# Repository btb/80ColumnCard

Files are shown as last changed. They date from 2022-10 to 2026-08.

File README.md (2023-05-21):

# 80ColumnCard
An 80-Column Card for the Apple II, II+, and clones.

This is mostly a clone of the Videx Videoterm, with some changes to reduce the number of chips needed.

[Interactive BOM](https://btb.github.io/80ColumnCard/hardware/80ColumnCard/bom/80ColumnCard_0.html)

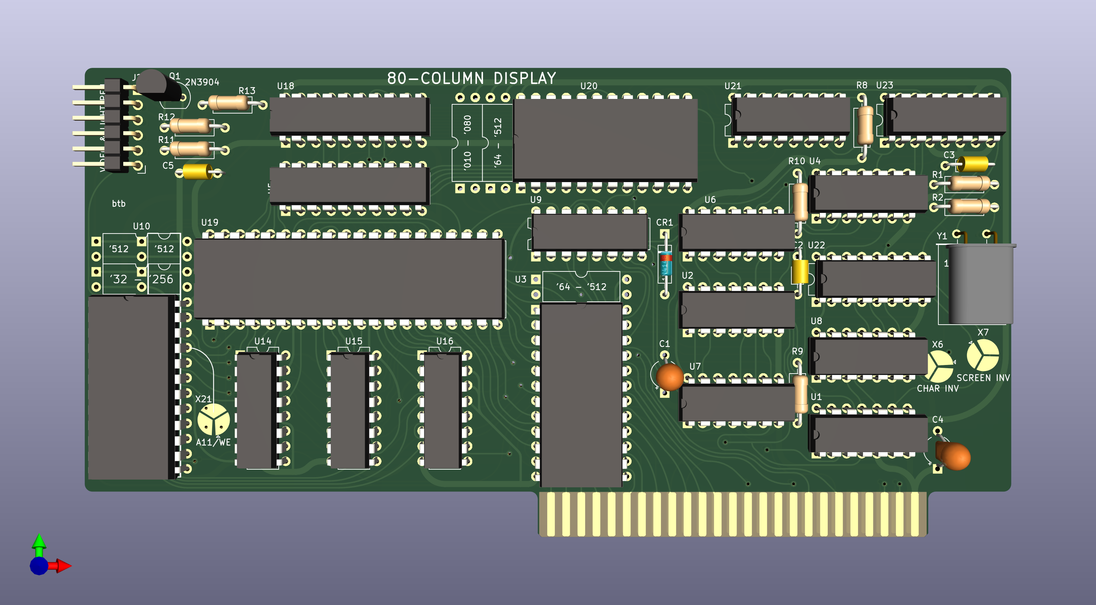
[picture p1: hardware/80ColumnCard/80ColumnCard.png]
rendering of 80 Column Card circuit board


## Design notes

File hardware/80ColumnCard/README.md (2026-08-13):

# 80ColumnCard

## Construction notes

## RAM (U10)
U10 is designed to use a 6116 Static RAM chip, however there are multiple overlapping footprints available on the board in order for you to just use whatever 2K or larger SRAM is easiest for you to obtain. Consult the interactive BOM if you're not sure how to place the chip. Many larger chips however have the A11 pin where the 6116 has the /WE pin, so you'll have to cut and then re-solder the X21 jumper accordingly.

## Firmware ROM (U3)
U3 holds the 1K of firmware (e.g. "Videx Videoterm ROM 2.4.bin") and can be any EPROM from a 2758A up to a 27(C)512, depending on whatever you have available. A10 will be permanently tied low, and A11-A15 are all permanently tied high, so the code needs to go in the lower 1K of a 2716, or the lower half of the top 2K of any larger EPROM. (Or just repeat it enough times to fill up the whole thing)

## Character ROM (U20)
Any size from 2732 to 27C512 (27C080 on rev0) is pin-compatible, however the character generator subcircuit appears to be very sensitive to the speed of this EPROM. Character corruption occurs with EPROMs that are too fast, so 200ns or slower (higher number) is recommended.
Confirmed working are: M27C64-20, AM2732A-2.

This EPROM can hold one or two of the 2K [character sets](../../character_roms). A12-A15 are all permanently tied high, so only the top 4K of the EPROM is usable. The standard character set (e.g. "videx std 7x9 - top right.bin") goes in the lower 2K of that space, and any desired alternative character set (e.g. "videx inverse - top left.bin") goes in the upper 2K of that space.

## Other
Although many of the TTL LS chips can be substituted with members of newer logic families (ACT, for example), U2 (74LS02) U4 (74LS04) U6 (74LS00) U23 (74LS161) must be LS or other TTL (non-CMOS) families.

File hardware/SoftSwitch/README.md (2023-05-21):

# SoftSwitch

A clone of the [Videx Soft Video Switch](../../documents/videx_soft_video_switch_manual.pdf)

[Interactive BOM](https://btb.github.io/80ColumnCard/hardware/SoftSwitch/bom/)

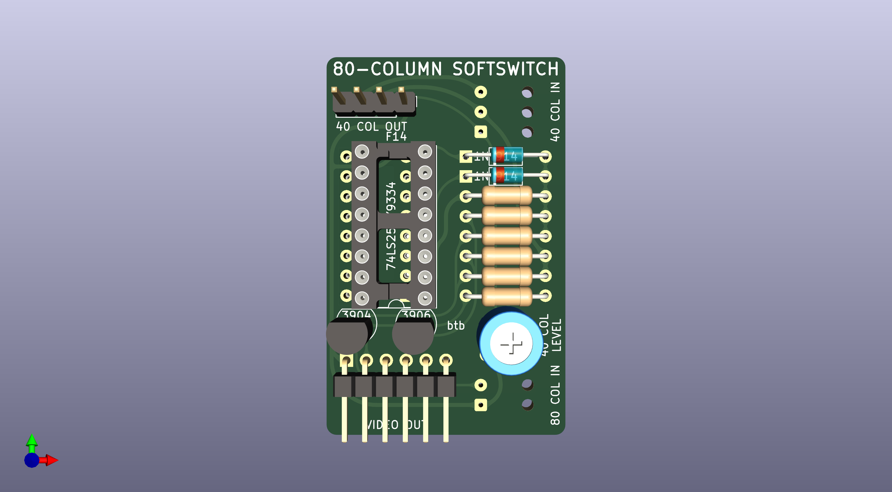
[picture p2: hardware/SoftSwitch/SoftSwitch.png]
rendering of SoftSwitch circuit board


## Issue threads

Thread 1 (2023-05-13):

Soft switch BOM doesn't display properly

baldrick1, 2023-05-13:
It appears you uploaded an html file for the soft switch BOM that's interactive.  But Github tries to display it as Raw HTML in its ecosystem.  Downloading the html file and opening it locally doesn't link to the actual data on the web.

btb, 2023-05-21:
Thanks for pointing that out. It is viewable through github.io, or it would have been if there wasn't a merge error in the file. It's now working at https://btb.github.io/80ColumnCard/hardware/SoftSwitch/bom/

Closed 2023-06-23.

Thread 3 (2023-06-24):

Finally built an 80 col card but the video is way out of sync and duplicated 4 times what could be the issue?

Verault, 2023-06-24:
So I finally got around to building one of the 80 col cards. When I do a pr#3 to go into 80 col mode the Sync is way, way off. I need to dial H Hold on my monitor to almost the extreme end to clear up video and as you can see from these photos the video output is duplicated in each corner of the screen. I can see a cursor but when I type it moves but there are no characters. I even tried using the roms from my original Videx card but it still is behaving thr same with those roms.

You can see the cursors on the inverse image. There are 4 cursors. And the non inverse image seems to be bouncing so the cursors ares slightly above each other. I circled them as to make them easier to see:
https://photos.app.goo.gl/85neNsyjyXsYRc43A
and
https://photos.app.goo.gl/yVLtZP9ghEdJ4nYZ8

A friend of mine is also building thr card. We ordered thr pcbs together. I am waiting on how his card behaves and will post back.

Again what is the issue here and why does the H Hold need to be completely adjusted out to get a video?

btb, 2023-06-24:
Interesting - can you tell me which firmware and what frequency crystal did you use?

The timings stored in different versions of firmware can vary and different timings may be needed for different monitors but I'm not sure it would result in this kind of problem. Still, you might want to see how it performs on different monitors just to check.

The sync circuitry is not very complicated, going directly from the 6845 (U19), pins 39 and 40, into the 74LS02 (U2) pins 2 and 3, out pin 1, and through R10, then it's mixed with the pixel data itself and goes into the output transistor Q1.

One possibility is that the 6845 just isn't outputting one of the sync signals - can you try swapping it? Same with the 74LS02.

I'm not much of an expert on the analog side of things, but the "mixing" of the sync with the pixel data is just a very simple voltage adder (averager) that could possibly be sensitive to the exact components used. Are U1 and U2 74LS series chips or something different like 74HCT? Can you verify the values of R9, R10, R11, R12, and R13? Replacing Q1 might be something to try if nothing else seems amiss.

Verault, 2023-06-24:
Ok. So for the firmware I used the Videx Videoterm ROM 2.4.bin and for the char rom I used the videx-std-7x9-topright.bin and the videx-inverse-topleft.bin with the std 7x9 rom being in the lower part of the eprom and teh videx inverse being in the top portion of the eprom. I used the bin files right from your github download and not outside files.

I am not using a softswitch.

I am using used 6845 IC's I bought online and have tried several. I even tried the one form my working videx card.. no change. ( I also swapped the used ones I bought on the original videx card and verified they were working.

I tested the 74ls03 and 74ls86 but I can try swapping them for a different brand just because I have plenty.

For reference U1 is a hitachi HD74ls86p and U2 is a generic 74ls02N

R9 is a 1.47K (1.5K) Ohm
r10 2K Ohm
r11 10 Ohm
r12 150 Ohm
r13 218 Ohm (I must have used a 220 ohm instead of a 200 ohm)

I was wondering if Q1 could be the issue. I can try swapping it for another 2N3904.

Just for reference I am using a Zenith monochrome composite monitor. Its my bench monitor and I used it for everything. I have plenty of other monitors I can try just to say we did that however I  jut want to point out that this zenith monitor outputs from my actual Videx card good 80 col video without having to adjust the H hold at all.

btb, 2023-06-24:
None of that seems amiss. I think that's the exact same crystal I used as well.

I do have a working card that I built and used with a Monitor III. You used my gerbers_0.zip file, right?

I just realized I missed in the original post that you have a real videx card and tried swapping the roms - As far as I know, the real Videx cards all used a 2708 EPROM for the firmware and you can't swap to a 2716 or similar without modifying the card. This could potentially have damaged your EPROM?

What eproms and sram chips are you using?
I only recently added this wiki page to clarify some things about the different chip requirements and where the data has to go, did you happen to see it?
https://github.com/btb/80ColumnCard/wiki/Parts

Verault, 2023-06-25:
The original Roms went back in the videx card and its still working perfectly fine.

The sram is HM6116L-70  12 pin

The eproms I am using are your run of the mill 27C64 which I have lots of. Like I mentioned I used your recommendation on the PARTS wiki and have the videx std 7 x 9 bin in the lower part of the eprom and the videx inverse in the top of the eprom. If there is a way I can upload or share the bin I created I can.

I have seen your PARTS wiki and have the 6116 in the lowest part of the socket down at the bottom of the board.

The only thing I was unsure about was the cutting of X21 jumper for A11. I didnt think my 6116 qualified for that.

btb, 2023-06-26:
You should be able to drop files here and I can look at them, yes. If you want to email me directly, it's bradley.bell at gmail.

You shouldn't need to change the jumper for a 6116.

Verault, 2023-06-26:
I wasnt aware I could add them here.
[Videx80colroms.zip](https://github.com/btb/80ColumnCard/files/11875155/Videx80colroms.zip)
These bins were made to use 27c64 eproms.

ryucats, 2023-06-27:
I've spent a week trying to get this card working, just managed to do so, and documented it in this pull request: https://github.com/btb/80ColumnCard/pull/4

I suspect that the horizontal timing in the firmware binary you're using is not playing nicely with your monitor; the same thing happened to me.  The timing data in the binary included in the firmware/ subdirectory is not stock; the pull request includes a .s file that can be modified to easily generate a binary with modified timing.

(most of the rest of the parts were scavenged from a faulty Sekom Videx clone, so I don't think your parts are bad, just that your timing parameters are incompatible with your monitor)

Not included in the pull request is a python script I wrote to derive timing register values from basic parameters -- I didn't include it because my problem turned out to be a) a character generator EPROM that was too fast and b) an incorrect assumption that the timing in the .bin in the firmware/ subdirectory was unmodified.  I can pass that script along if you want to play with it.

btb, 2023-06-27:
yeah, those files should work. That risk of damage I think would only be if you put your newly-burned ROM into your original Videx but it doesn't sound like you did that. (and a 2764 wouldn't fit of course!)

My apologies for the trouble you're having, I'm really not sure what the problem is. I'm used to just building things for myself, putting them out there for everyone else is kinda new for me. Maybe you could send me your card and I'll get it working for you. That would allow me to see what the pitfalls happen to be so others will avoid it.

ryucats, 2023-06-27:
Just had a look at the timing in the zipfile you attached.  At offset $A1, you have:

`7a 50 5e 2f 22 00 18 1d 00 08 e0 08 00 00 00 00`

Try:

`7b 50 5e 29 1b 08 18 19 00 08 e0 08 00 00 00 00`

... which is per the Videx documentation and fixed my horizontal sync issues.

btb, 2023-06-27:
Yeah, that's worth a try. That may fix the sync issue, and then a slower character ROM is needed to get the characters to show up...

I used an old 27C32 in mine, and it looks like @ryucats used a M27C64-200.

btb, 2023-06-27:
Sounds like you may have already tried U20 from your videx card in the new card and it didn't result in visible characters - but that might have been because it's a 2716 and those isn't supported on this card (A11 is needed to switch between standard and alternate character sets, and that line will instead go to VPP on a 2716) - but it is possible that that the Videx character rom chip will work, but only when you tell the card to use the alternate character set.

ryucats, 2023-06-27:
>Wouldn't they still expect to see some signs of characters even if the timing is wrong?

Independent of timing issues, If @verault is using a too-fast character EPROM, or a 2716 as you noted, then he'd either see garbage or a blank screen (except for the cursor) ... which is exactly what those pictures appear to be.
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
btb, 2023-06-28:
I double-checked on my card and it is using the
    7a 50 5e 2f 22 00 18  1d 00 08 e0 08 00 00 00 00
timings, and it definitely works on my Monitor IIe, FWIW. Doesn't work on the LCD tv I just picked up though.

Verault, 2023-06-28:
Sorry for not chiming back in. I have been ill. Good to see alot of discussion about the issue. I am going to try the new code in the firmware first. (By the way which rom are we talking about U20 or U3?)

Also I guess the eprom latency makes sense being an issue but this creates a huge problem of its own. I buy alot of eproms and MOST of them work, but have been re-badged. For instance my 27c64 eproms all say ST brand 27c64 but thier Chip ID's come up with a bunch of different manufacturers. So how can I possible find a trustworthy M27C64-200 with 200 latency? Do you possibly have a source I can purchase from thats reputable?

btb, 2023-06-28:
Here's a copy of the firmware for U3, with the stock timings and ready to go on a 2764
[Videx_Videoterm_ROM_2.4-stocktimings-2764.bin.zip](https://github.com/btb/80ColumnCard/files/11899147/Videx_Videoterm_ROM_2.4-stocktimings-2764.bin.zip)

Verault, 2023-06-28:
Thank you. And just to confirm the only eprom which is sensitive to latency is u20?

Verault, 2023-07-07:
Ok @btb and @ryucats I am sorry for the delay in replying but I have more info. I had a friend of mine who is building the same 80 col board mail it to me so I can test his as well. ITs basically behaving the same as mine except his is showing 6 screens (and again no characters) see photo.
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

Im at a complete loss on this. I have MANY MANY eproms of various sizes but like I said most have been relabeled so the only way to know the actual brand is to read the CHIP ID in my eprom programmer but that wont tell me the latency/speed.  I bought some AMD 27c512-200DC (thats 200ns correct) and I am getting the same exact image,.,, multiple screens inverted, no characters, very much out of sync.

@ryucats I have tried the stock and the timings you recommended. Please see the newest bins I burned , ill attach them here.

Did I mess up in making them?

I really want these boards to work but I dont know what is wrong at this point. I tried many eproms. I even tried some SST 27SF256 EEPROMS with the same results.

btb, 2023-07-07:
send me your address and I'll mail you a couple of known-working character roms

Verault, 2023-07-08:
Thank you. I just emailed you.

btb, 2023-08-01:
Well we found the problem on Verault's card, and it was due to a "bad" 74LS04 chip.
I have some of the same chips in my collection and they don't work for me either, It's possible these are counterfeit chips being sold as LS when they are actually some other type of logic. This is what they look like:
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

The 74LS04 is used in the clock circuit, which is another sensitive area. Possibly these chips, or a wider range of logic families, could be made to work with different values of C3 or R1 and R2.

Verault, 2023-09-08:
BTB is correct. The issue was the 74ls04 chips. They must be some relabeled nonsense from China. They test fine but dont work properly in this card. I ordered new ones from Jameco and they work fine, as the one I received back from BTB. Thank you so much for your help. That was an odd one. Issue resolved.

Closed 2023-09-08.

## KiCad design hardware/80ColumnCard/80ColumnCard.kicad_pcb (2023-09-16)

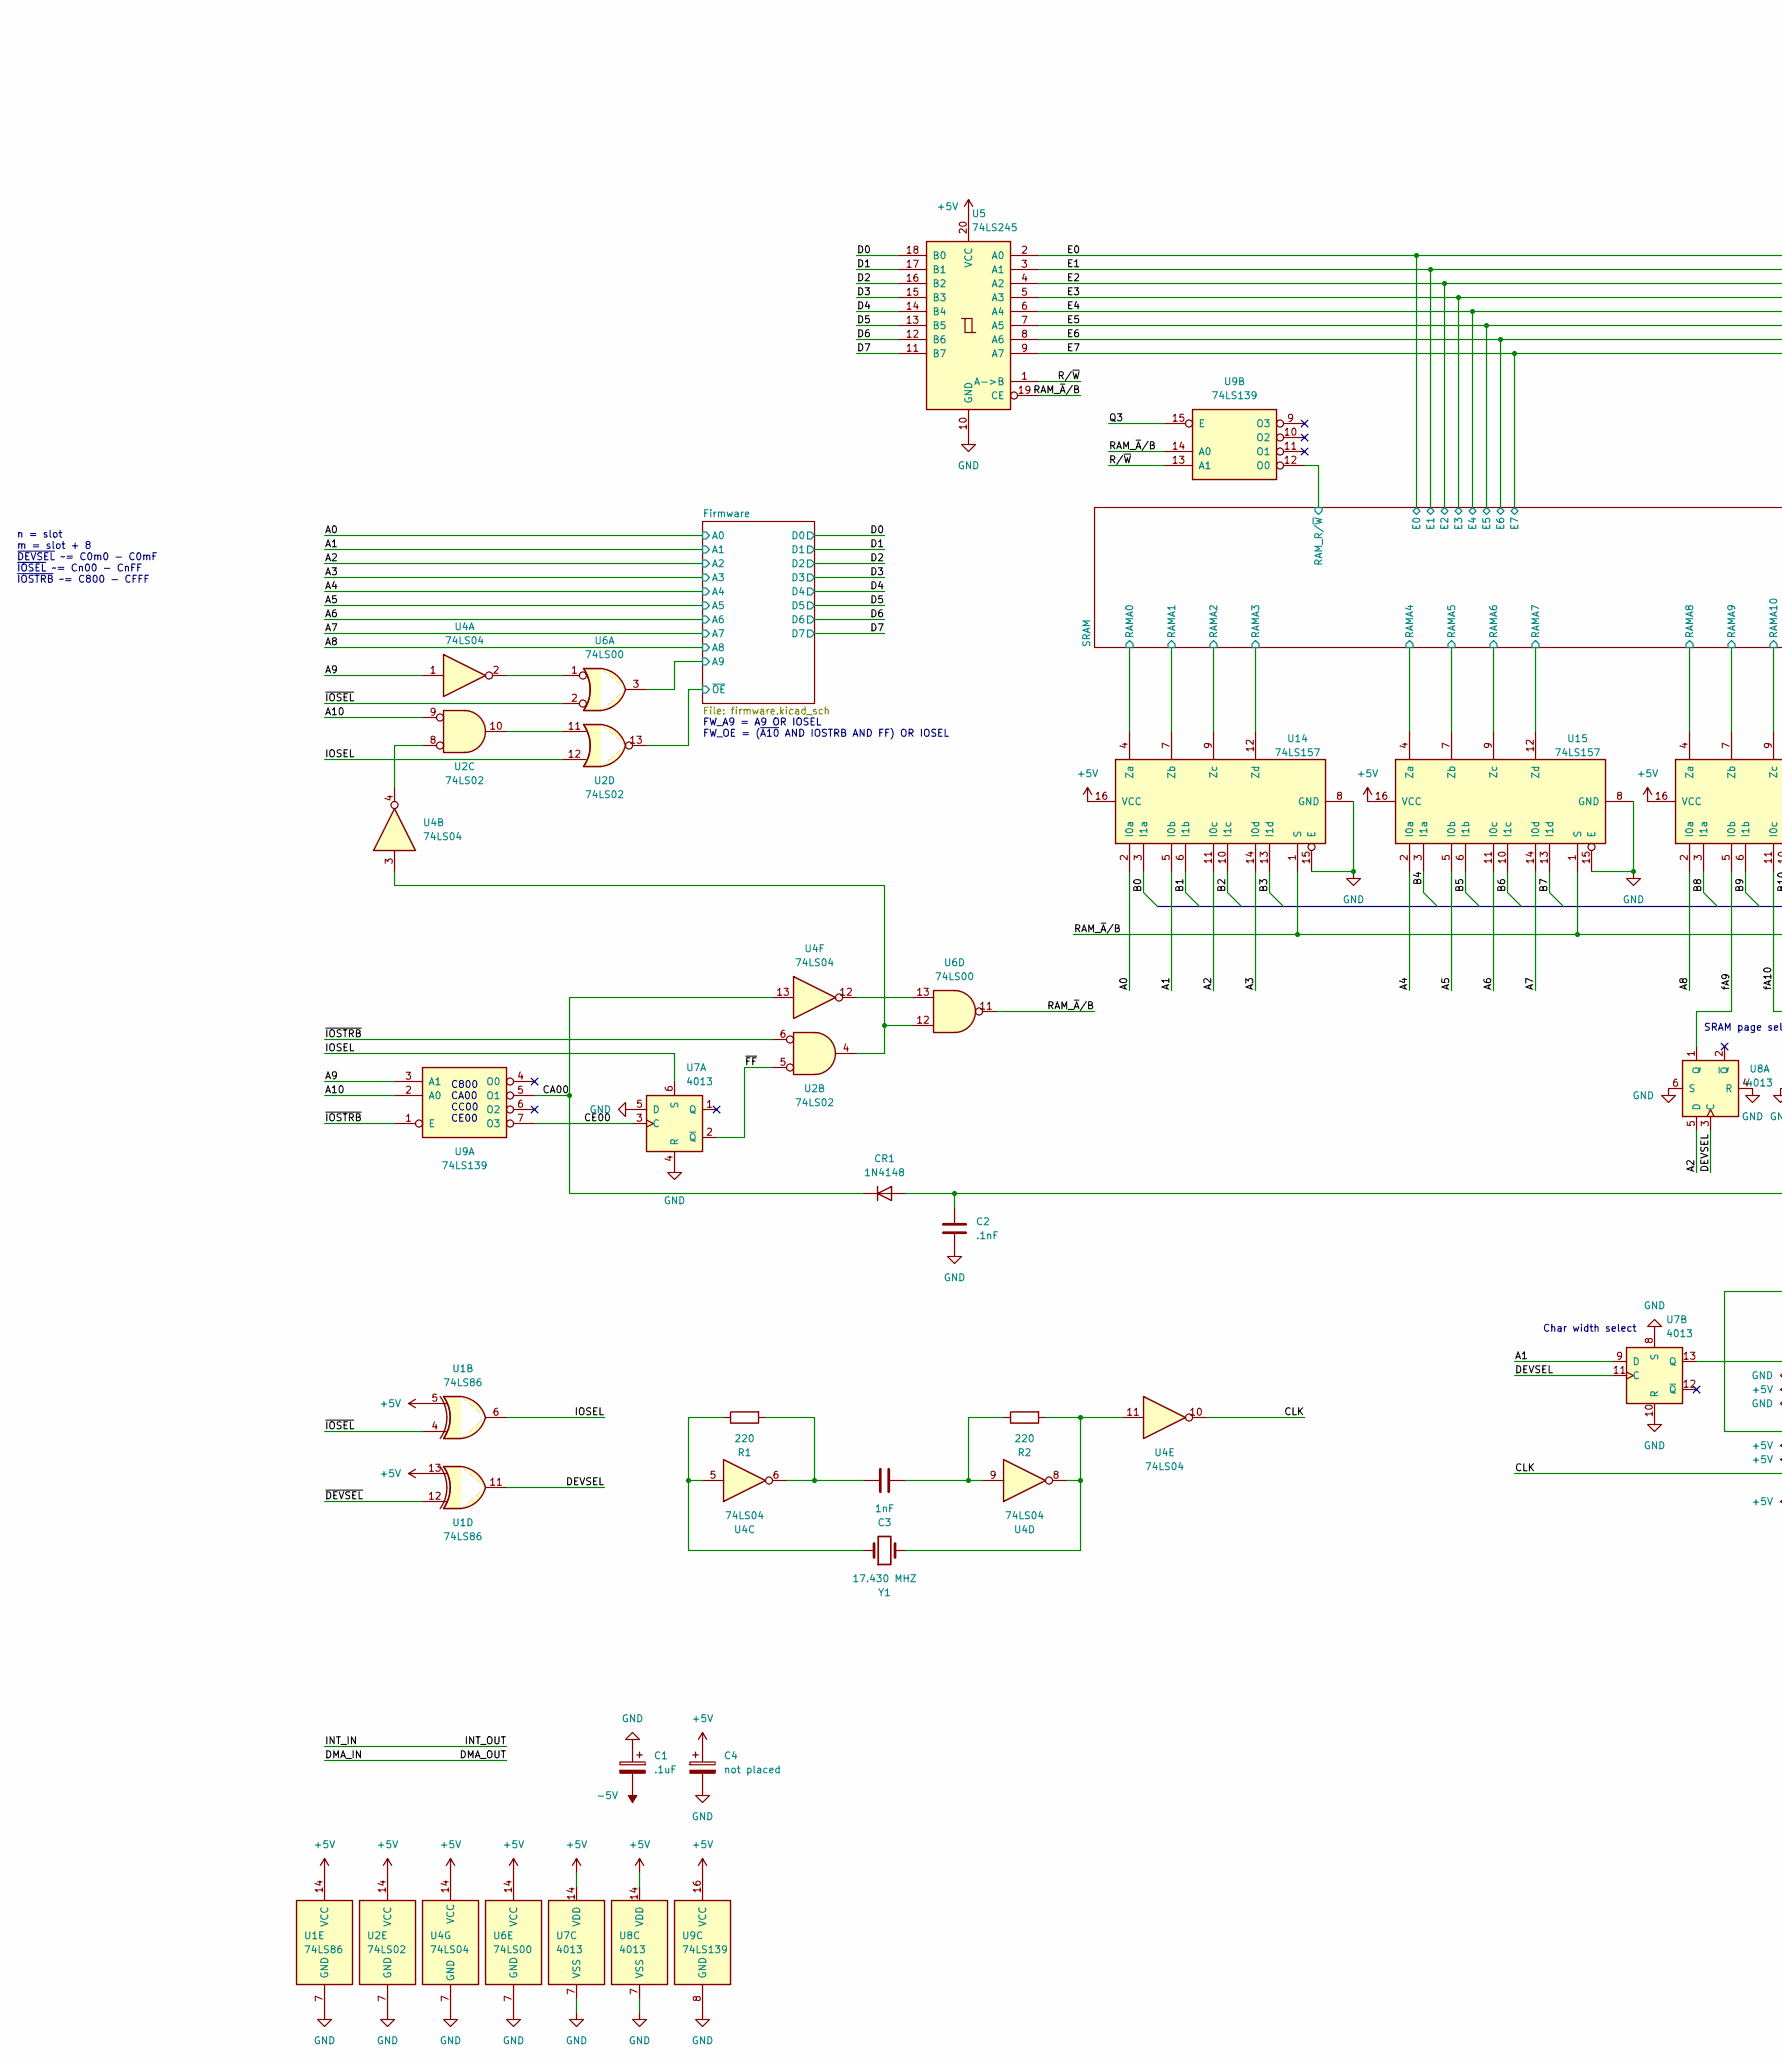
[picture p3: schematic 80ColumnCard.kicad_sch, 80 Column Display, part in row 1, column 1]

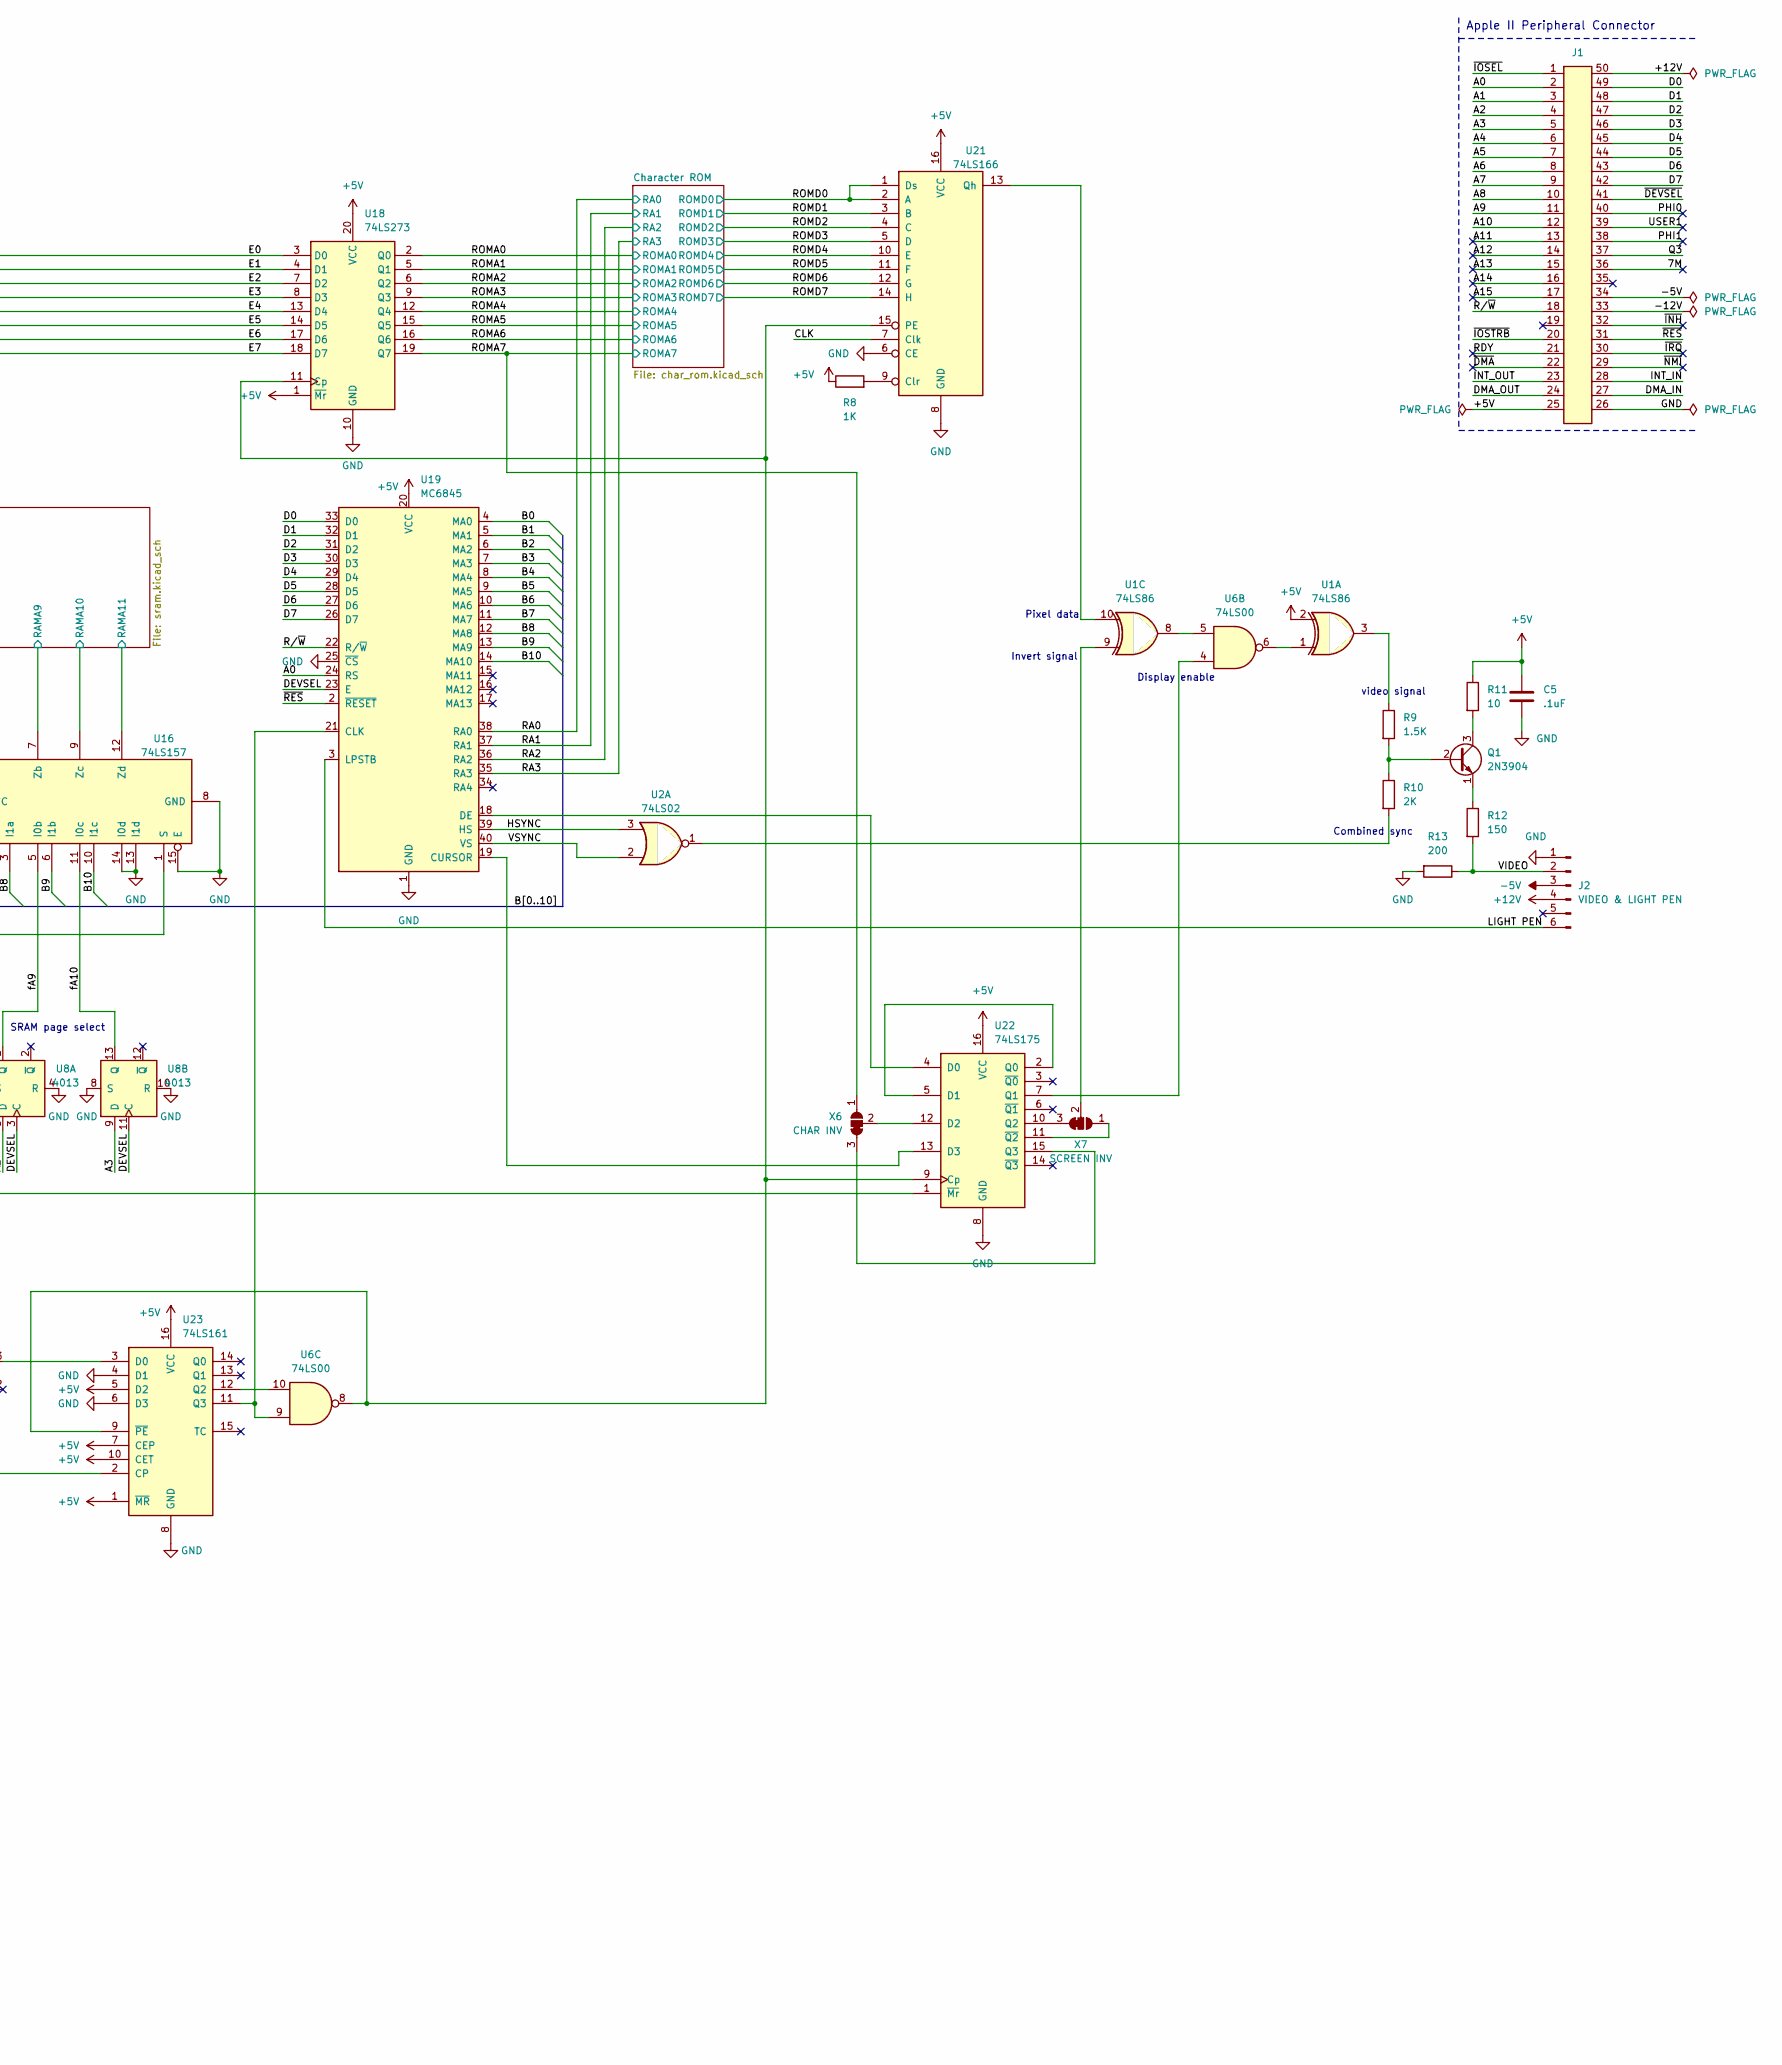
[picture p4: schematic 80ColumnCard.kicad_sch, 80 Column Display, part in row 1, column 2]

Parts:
C1: .1uF; CP_Radial_Tantal_D4.5mm_P6.35mm
C2: .1nF; C_Axial_L2.6mm_D1.8mm_P6.35mm_Horizontal
C3: 1nF; C_Axial_L2.6mm_D1.8mm_P6.35mm_Horizontal
C4: not placed; CP_Radial_Tantal_D4.5mm_P6.35mm
C5: .1uF; C_Axial_L2.6mm_D1.8mm_P6.35mm_Horizontal
CR1: 1N4148; D_DO-35_SOD27_P10.16mm_Horizontal
J1: Apple II Expansion Bus; Apple II Expansion Edge Connector
J2: VIDEO & LIGHT PEN; PinHeader_1x06_P2.54mm_Horizontal
Q1: 2N3904; TO-92
R1, R2: 220; R_Axial_DIN0207_L6.3mm_D2.5mm_P10.16mm_Horizontal
R8: 1K; R_Axial_DIN0207_L6.3mm_D2.5mm_P10.16mm_Horizontal
R9: 1.5K; R_Axial_DIN0207_L6.3mm_D2.5mm_P10.16mm_Horizontal
R10: 2K; R_Axial_DIN0207_L6.3mm_D2.5mm_P10.16mm_Horizontal
R11: 10; R_Axial_DIN0207_L6.3mm_D2.5mm_P10.16mm_Horizontal
R12: 150; R_Axial_DIN0207_L6.3mm_D2.5mm_P10.16mm_Horizontal
R13: 200; R_Axial_DIN0207_L6.3mm_D2.5mm_P10.16mm_Horizontal
U1: 74LS86; DIP-14_W7.62mm
U2: 74LS02; DIP-14_W7.62mm
U4: 74LS04; DIP-14_W7.62mm
U5: 74LS245; DIP-20_W7.62mm
U6: 74LS00; DIP-14_W7.62mm
U7, U8: 4013; DIP-14_W7.62mm
U9: 74LS139; DIP-16_W7.62mm
U14, U15, U16: 74LS157; DIP-16_W7.62mm
U18: 74LS273; DIP-20_W7.62mm
U19: MC6845; DIP-40_W15.24mm
U21: 74LS166; DIP-16_W7.62mm
U22: 74LS175; DIP-16_W7.62mm
U23: 74LS161; DIP-16_W7.62mm
X6: CHAR INV; SolderJumper-3_Pie_Bridged23
X7: SCREEN INV; SolderJumper-3_Pie_Bridged23
Y1: 17.430 MHZ; Crystal_HC18-U_Horizontal

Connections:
+5V: C4.1, C5.1, J1.25 (+5V), R8.1, R11.1, U1.2, U1.5, U1.13, U1.14 (VCC), U2.14 (VCC), U4.14 (VCC), U5.20 (VCC), U6.14 (VCC), U7.14 (VDD), U8.14 (VDD), U9.16 (VCC), U14.16 (VCC), U15.16 (VCC), U16.16 (VCC), U18.1 (~Mr), U18.20 (VCC), U19.20 (VCC), U21.16 (VCC), U22.16 (VCC), U23.1 (~MR), U23.5 (D2), U23.7 (CEP), U23.10 (CET), U23.16 (VCC); also elsewhere on the board
+12V: J1.50 (-12V), J2.4
-5V: C1.2, J1.34 (-5V), J2.3
/7M: J1.36 (7M)
/-12V: J1.33 (-12V)
/A0: J1.2 (A00), U14.2 (I0a), U19.24 (RS); also elsewhere on the board
/A1: J1.3 (A01), U7.9 (D), U14.5 (I0b); also elsewhere on the board
/A2: J1.4 (A02), U8.5 (D), U14.11 (I0c); also elsewhere on the board
/A3: J1.5 (A03), U8.9 (D), U14.14 (I0d); also elsewhere on the board
/A4: J1.6 (A04), U15.2 (I0a); also elsewhere on the board
/A5: J1.7 (A05), U15.5 (I0b); also elsewhere on the board
/A6: J1.8 (A06), U15.11 (I0c); also elsewhere on the board
/A7: J1.9 (A07), U15.14 (I0d); also elsewhere on the board
/A8: J1.10 (A08), U16.2 (I0a); also elsewhere on the board
/A9: J1.11 (A09), U4.1, U9.3 (A1)
/A10: J1.12 (A10), U2.9, U9.2 (A0)
/A11: J1.13 (A11)
/A12: J1.14 (A12)
/A13: J1.15 (A13)
/A14: J1.16 (A14)
/A15: J1.17 (A15)
/B0: U14.3 (I1a), U19.4 (MA0)
/B1: U14.6 (I1b), U19.5 (MA1)
/B2: U14.10 (I1c), U19.6 (MA2)
/B3: U14.13 (I1d), U19.7 (MA3)
/B4: U15.3 (I1a), U19.8 (MA4)
/B5: U15.6 (I1b), U19.9 (MA5)
/B6: U15.10 (I1c), U19.10 (MA6)
/B7: U15.13 (I1d), U19.11 (MA7)
/B8: U16.3 (I1a), U19.12 (MA8)
/B9: U16.6 (I1b), U19.13 (MA9)
/B10: U16.10 (I1c), U19.14 (MA10)
/CA00: CR1.1 (K), U4.13, U9.5 (O1)
/CE00: U7.3 (C), U9.7 (O3)
/CLK: U4.10, U21.7 (Clk), U23.2 (CP)
/D0: J1.49 (D0), U5.18 (B0), U19.33 (D0); also elsewhere on the board
/D1: J1.48 (D1), U5.17 (B1), U19.32 (D1); also elsewhere on the board
/D2: J1.47 (D2), U5.16 (B2), U19.31 (D2); also elsewhere on the board
/D3: J1.46 (D3), U5.15 (B3), U19.30 (D3); also elsewhere on the board
/D4: J1.45 (D4), U5.14 (B4), U19.29 (D4); also elsewhere on the board
/D5: J1.44 (D5), U5.13 (B5), U19.28 (D5); also elsewhere on the board
/D6: J1.43 (D6), U5.12 (B6), U19.27 (D6); also elsewhere on the board
/D7: J1.42 (D7), U5.11 (B7), U19.26 (D7); also elsewhere on the board
/DEVSEL: U1.11, U7.11 (C), U8.3 (C), U8.11 (C), U19.23 (E)
/DMA_IN: J1.24 (DMA_OUT), J1.27 (DMA_IN)
/E0: U5.2 (A0), U18.3 (D0); also elsewhere on the board
/E1: U5.3 (A1), U18.4 (D1); also elsewhere on the board
/E2: U5.4 (A2), U18.7 (D2); also elsewhere on the board
/E3: U5.5 (A3), U18.8 (D3); also elsewhere on the board
/E4: U5.6 (A4), U18.13 (D4); also elsewhere on the board
/E5: U5.7 (A5), U18.14 (D5); also elsewhere on the board
/E6: U5.8 (A6), U18.17 (D6); also elsewhere on the board
/E7: U5.9 (A7), U18.18 (D7); also elsewhere on the board
/Firmware/A9: U6.3; also elsewhere on the board
/Firmware/~OE: U2.13; also elsewhere on the board
/HSYNC: U2.3, U19.39 (HS)
/INT_IN: J1.23 (INT_OUT), J1.28 (INT_IN)
/IOSEL: U1.6, U2.12, U7.6 (S)
/LIGHT PEN: J2.6, U19.3 (LPSTB)
/PHI0: J1.40 (PHI0)
/PHI1: J1.38 (PHI1)
/Q3: J1.37 (Q3), U9.15 (E)
/RA0: U19.38 (RA0); also elsewhere on the board
/RA1: U19.37 (RA1); also elsewhere on the board
/RA2: U19.36 (RA2); also elsewhere on the board
/RA3: U19.35 (RA3); also elsewhere on the board
/RAM_~A/B: U5.19 (CE), U6.11, U9.14 (A0), U14.1 (S), U15.1 (S), U16.1 (S)
/RDY: J1.21 (RDY)
/ROMA0: U18.2 (Q0); also elsewhere on the board
/ROMA1: U18.5 (Q1); also elsewhere on the board
/ROMA2: U18.6 (Q2); also elsewhere on the board
/ROMA3: U18.9 (Q3); also elsewhere on the board
/ROMA4: U18.12 (Q4); also elsewhere on the board
/ROMA5: U18.15 (Q5); also elsewhere on the board
/ROMA6: U18.16 (Q6); also elsewhere on the board
/ROMA7: U18.19 (Q7), X6.1 (A); also elsewhere on the board
/ROMD0: U21.1 (Ds), U21.2 (A); also elsewhere on the board
/ROMD1: U21.3 (B); also elsewhere on the board
/ROMD2: U21.4 (C); also elsewhere on the board
/ROMD3: U21.5 (D); also elsewhere on the board
/ROMD4: U21.10 (E); also elsewhere on the board
/ROMD5: U21.11 (F); also elsewhere on the board
/ROMD6: U21.12 (G); also elsewhere on the board
/ROMD7: U21.14 (H); also elsewhere on the board
/R/~W: J1.18 (R/~W), U5.1 (A->B), U9.13 (A1), U19.22 (R/~W)
/SRAM/RAMA0: U14.4 (Za); also elsewhere on the board
/SRAM/RAMA1: U14.7 (Zb); also elsewhere on the board
/SRAM/RAMA2: U14.9 (Zc); also elsewhere on the board
/SRAM/RAMA3: U14.12 (Zd); also elsewhere on the board
/SRAM/RAMA4: U15.4 (Za); also elsewhere on the board
/SRAM/RAMA5: U15.7 (Zb); also elsewhere on the board
/SRAM/RAMA6: U15.9 (Zc); also elsewhere on the board
/SRAM/RAMA7: U15.12 (Zd); also elsewhere on the board
/SRAM/RAMA8: U16.4 (Za); also elsewhere on the board
/SRAM/RAMA9: U16.7 (Zb); also elsewhere on the board
/SRAM/RAMA10: U16.9 (Zc); also elsewhere on the board
/SRAM/RAMA11: U16.12 (Zd); also elsewhere on the board
/SRAM/RAM_R/~W: U9.12 (O0); also elsewhere on the board
/USER1: J1.39 (USER1)
/VIDEO: J2.2, R12.2, R13.1
/VSYNC: U2.2, U19.40 (VS)
/fA9: U8.1 (Q), U16.5 (I0b)
/fA10: U8.13 (Q), U16.11 (I0c)
/~DEVSEL: J1.41 (~DEVICE_SELECT), U1.12
/~DMA: J1.22 (~DMA)
/~FF: U2.5, U7.2 (~Q)
/~INH: J1.32 (~INH)
/~IOSEL: J1.1 (~IO_SELECT), U1.4, U6.2
/~IOSTRB: J1.20 (~I/O_STROBE), U2.6, U9.1 (E)
/~IRQ: J1.30 (~IRQ)
/~NMI: J1.29 (~NMI)
/~RES: J1.31 (~RES), U19.2 (~RESET)
GND: C1.1, C2.2, C4.2, C5.2, J1.26 (GND), J2.1, R13.2, U1.7 (GND), U2.7 (GND), U4.7 (GND), U5.10 (GND), U6.7 (GND), U7.4 (R), U7.5 (D), U7.7 (VSS), U7.8 (S), U7.10 (R), U8.4 (R), U8.6 (S), U8.7 (VSS), U8.8 (S), U8.10 (R), U9.8 (GND), U14.8 (GND), U14.15 (E), U15.8 (GND), U15.15 (E), U16.8 (GND), U16.13 (I1d), U16.14 (I0d), U16.15 (E), U18.10 (GND), U19.1 (GND), U19.25 (~CS), U21.6 (CE), U21.8 (GND), U22.8 (GND), U23.4 (D1), U23.6 (D3), U23.8 (GND); also elsewhere on the board
unnamed: C2.1, CR1.2 (A), U22.1 (~Mr)
unnamed: C3.1, R1.2, U4.6
unnamed: C3.2, R2.1, U4.9
unnamed: Q1.1 (E), R12.1
unnamed: Q1.2 (B), R9.2, R10.1
unnamed: Q1.3 (C), R11.2
unnamed: R1.1, U4.5, Y1.1
unnamed: R2.2, U4.8, U4.11, Y1.2
unnamed: R8.2, U21.9 (Clr)
unnamed: R9.1, U1.3
unnamed: R10.2, U2.1
unnamed: U1.1, U6.6
unnamed: U1.8, U6.5
unnamed: U1.9, X7.2 (C)
unnamed: U1.10, U21.13 (Qh)
unnamed: U2.4, U4.3, U6.12
unnamed: U2.8, U4.4
unnamed: U2.10, U2.11
unnamed: U4.2, U6.1
unnamed: U4.12, U6.13
unnamed: U6.8, U18.11 (Cp), U21.15 (PE), U22.9 (Cp), U23.9 (~PE)
unnamed: U19.18 (DE), U22.4 (D0)
unnamed: U19.19 (CURSOR), U22.13 (D3)
unnamed: U6.9, U19.21 (CLK), U23.11 (Q3)
unnamed: U22.2 (Q0), U22.5 (D1)
unnamed: U6.4, U22.7 (Q1)
unnamed: U22.10 (Q2), X7.3 (B)
unnamed: U22.11 (~Q2), X7.1 (A)
unnamed: U22.12 (D2), X6.2 (C)
unnamed: U22.15 (Q3), X6.3 (B)
unnamed: U7.13 (Q), U23.3 (D0)
unnamed: U6.10, U23.12 (Q2)

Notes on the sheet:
Display enable
Apple II Peripheral Connector
Invert signal
n = slot m = slot + 8 ~{DEVSEL} ~= C0m0 - C0mF ~{IOSEL} ~= Cn00 - CnFF ~{IOSTRB} ~= C800 - CFFF
SRAM page select
Char width select
C800 CA00 CC00 CE00
Combined sync
video signal
Pixel data
FW_A9 = A9 OR IOSEL FW_OE = (~{A10} AND IOSTRB AND FF) OR IOSEL

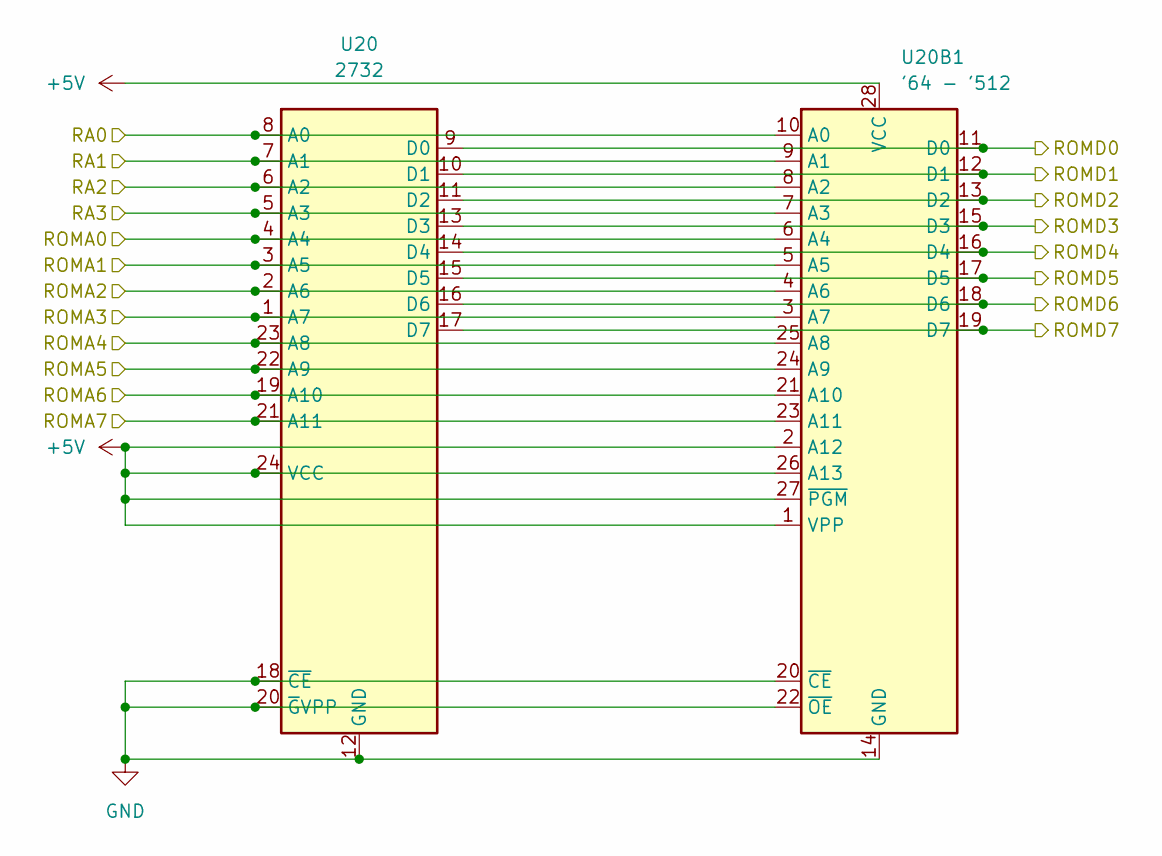
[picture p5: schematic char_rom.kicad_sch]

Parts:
U20: 2732; DIP-24_W15.24mm
U20B1: '64 - '512; DIP-28_W15.24mm

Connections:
+5V: U20.24 (VCC), U20B1.1 (VPP), U20B1.2 (A12), U20B1.26 (A13), U20B1.27 (~PGM), U20B1.28 (VCC); also elsewhere on the board
/RA0: U20.8 (A0), U20B1.10 (A0); also elsewhere on the board
/RA1: U20.7 (A1), U20B1.9 (A1); also elsewhere on the board
/RA2: U20.6 (A2), U20B1.8 (A2); also elsewhere on the board
/RA3: U20.5 (A3), U20B1.7 (A3); also elsewhere on the board
/ROMA0: U20.4 (A4), U20B1.6 (A4); also elsewhere on the board
/ROMA1: U20.3 (A5), U20B1.5 (A5); also elsewhere on the board
/ROMA2: U20.2 (A6), U20B1.4 (A6); also elsewhere on the board
/ROMA3: U20.1 (A7), U20B1.3 (A7); also elsewhere on the board
/ROMA4: U20.23 (A8), U20B1.25 (A8); also elsewhere on the board
/ROMA5: U20.22 (A9), U20B1.24 (A9); also elsewhere on the board
/ROMA6: U20.19 (A10), U20B1.21 (A10); also elsewhere on the board
/ROMA7: U20.21 (A11), U20B1.23 (A11); also elsewhere on the board
/ROMD0: U20.9 (D0), U20B1.11 (D0); also elsewhere on the board
/ROMD1: U20.10 (D1), U20B1.12 (D1); also elsewhere on the board
/ROMD2: U20.11 (D2), U20B1.13 (D2); also elsewhere on the board
/ROMD3: U20.13 (D3), U20B1.15 (D3); also elsewhere on the board
/ROMD4: U20.14 (D4), U20B1.16 (D4); also elsewhere on the board
/ROMD5: U20.15 (D5), U20B1.17 (D5); also elsewhere on the board
/ROMD6: U20.16 (D6), U20B1.18 (D6); also elsewhere on the board
/ROMD7: U20.17 (D7), U20B1.19 (D7); also elsewhere on the board
GND: U20.12 (GND), U20.18 (~CE), U20.20 (~GVPP), U20B1.14 (GND), U20B1.20 (~CE), U20B1.22 (~OE); also elsewhere on the board

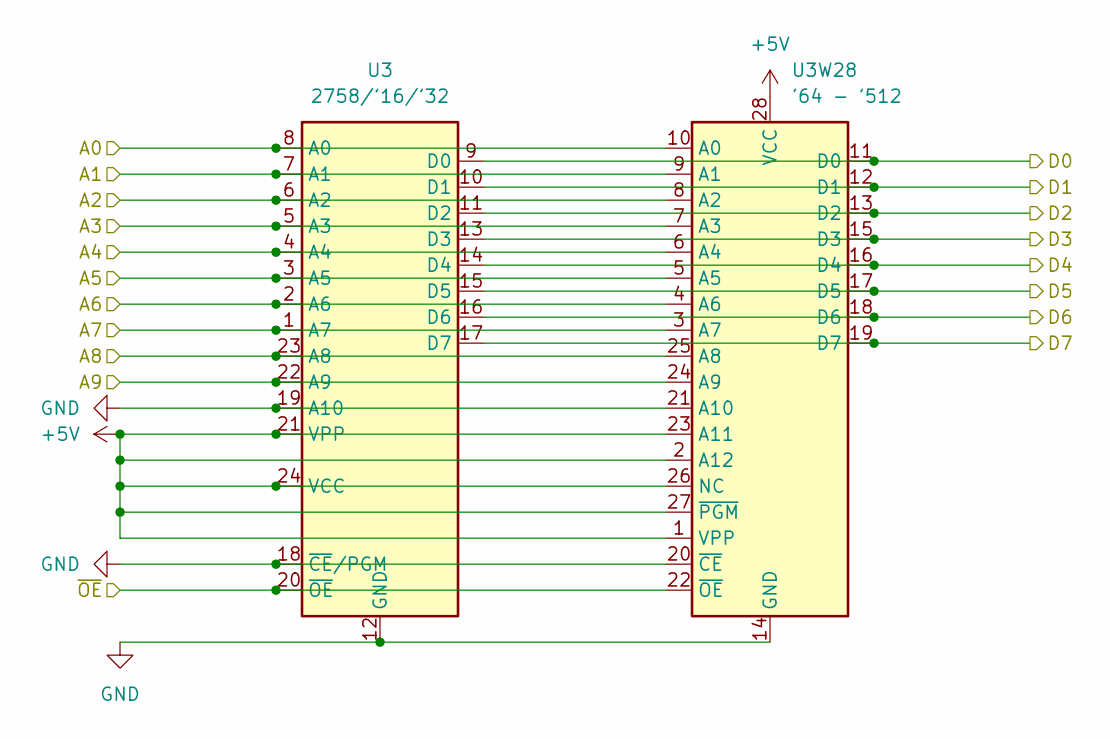
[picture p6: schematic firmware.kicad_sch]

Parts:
U3: 2758/'16/'32; DIP-24_W15.24mm
U3W28: '64 - '512; DIP-28_W15.24mm

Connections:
+5V: U3.21 (VPP), U3.24 (VCC), U3W28.1 (VPP), U3W28.2 (A12), U3W28.23 (A11), U3W28.26 (NC), U3W28.27 (~PGM), U3W28.28 (VCC); also elsewhere on the board
/A0: U3.8 (A0), U3W28.10 (A0); also elsewhere on the board
/A1: U3.7 (A1), U3W28.9 (A1); also elsewhere on the board
/A2: U3.6 (A2), U3W28.8 (A2); also elsewhere on the board
/A3: U3.5 (A3), U3W28.7 (A3); also elsewhere on the board
/A4: U3.4 (A4), U3W28.6 (A4); also elsewhere on the board
/A5: U3.3 (A5), U3W28.5 (A5); also elsewhere on the board
/A6: U3.2 (A6), U3W28.4 (A6); also elsewhere on the board
/A7: U3.1 (A7), U3W28.3 (A7); also elsewhere on the board
/A8: U3.23 (A8), U3W28.25 (A8); also elsewhere on the board
/D0: U3.9 (D0), U3W28.11 (D0); also elsewhere on the board
/D1: U3.10 (D1), U3W28.12 (D1); also elsewhere on the board
/D2: U3.11 (D2), U3W28.13 (D2); also elsewhere on the board
/D3: U3.13 (D3), U3W28.15 (D3); also elsewhere on the board
/D4: U3.14 (D4), U3W28.16 (D4); also elsewhere on the board
/D5: U3.15 (D5), U3W28.17 (D5); also elsewhere on the board
/D6: U3.16 (D6), U3W28.18 (D6); also elsewhere on the board
/D7: U3.17 (D7), U3W28.19 (D7); also elsewhere on the board
/Firmware/A9: U3.22 (A9), U3W28.24 (A9); also elsewhere on the board
/Firmware/~OE: U3.20 (~OE), U3W28.22 (~OE); also elsewhere on the board
GND: U3.12 (GND), U3.18 (~CE/PGM), U3.19 (A10), U3W28.14 (GND), U3W28.20 (~CE), U3W28.21 (A10); also elsewhere on the board

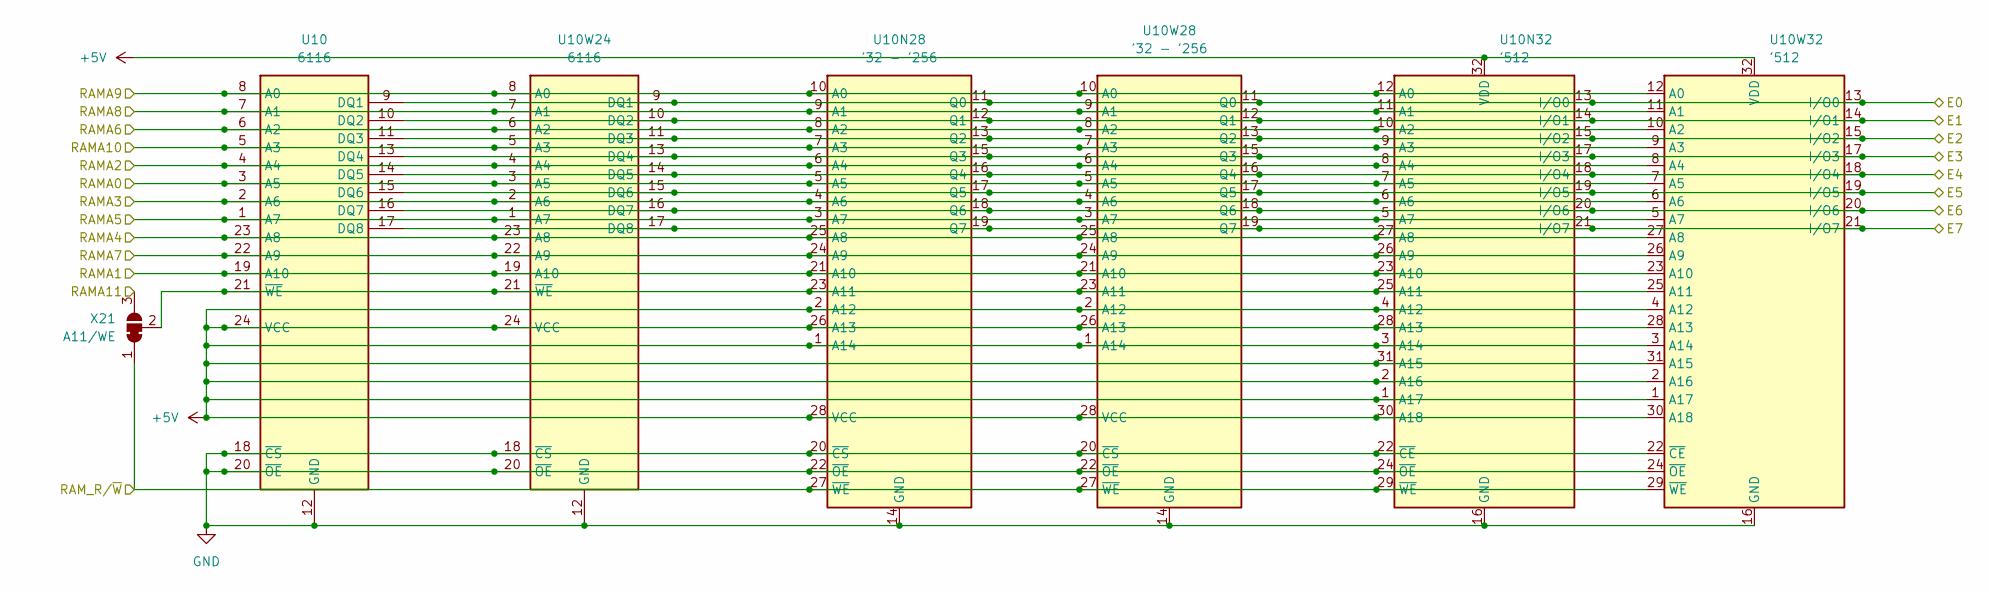
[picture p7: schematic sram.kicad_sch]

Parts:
U10: 6116; DIP-24_W7.62mm
U10N28: '32 - '256; DIP-28_W7.62mm
U10N32: '512; DIP-32_W7.62mm
U10W24: 6116; DIP-24_W15.24mm
U10W28: '32 - '256; DIP-28_W15.24mm
U10W32: '512; DIP-32_W15.24mm
X21: A11/WE; SolderJumper-3_Pie_Bridged12

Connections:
+5V: U10.24 (VCC), U10N28.1 (A14), U10N28.2 (A12), U10N28.26 (A13), U10N28.28 (VCC), U10N32.1 (A17), U10N32.2 (A16), U10N32.3 (A14), U10N32.4 (A12), U10N32.28 (A13), U10N32.30 (A18), U10N32.31 (A15), U10N32.32 (VDD), U10W24.24 (VCC), U10W28.1 (A14), U10W28.2 (A12), U10W28.26 (A13), U10W28.28 (VCC), U10W32.1 (A17), U10W32.2 (A16), U10W32.3 (A14), U10W32.4 (A12), U10W32.28 (A13), U10W32.30 (A18), U10W32.31 (A15), U10W32.32 (VDD); also elsewhere on the board
/E0: U10.9 (DQ1), U10N28.11 (Q0), U10N32.13 (I/O0), U10W24.9 (DQ1), U10W28.11 (Q0), U10W32.13 (I/O0); also elsewhere on the board
/E1: U10.10 (DQ2), U10N28.12 (Q1), U10N32.14 (I/O1), U10W24.10 (DQ2), U10W28.12 (Q1), U10W32.14 (I/O1); also elsewhere on the board
/E2: U10.11 (DQ3), U10N28.13 (Q2), U10N32.15 (I/O2), U10W24.11 (DQ3), U10W28.13 (Q2), U10W32.15 (I/O2); also elsewhere on the board
/E3: U10.13 (DQ4), U10N28.15 (Q3), U10N32.17 (I/O3), U10W24.13 (DQ4), U10W28.15 (Q3), U10W32.17 (I/O3); also elsewhere on the board
/E4: U10.14 (DQ5), U10N28.16 (Q4), U10N32.18 (I/O4), U10W24.14 (DQ5), U10W28.16 (Q4), U10W32.18 (I/O4); also elsewhere on the board
/E5: U10.15 (DQ6), U10N28.17 (Q5), U10N32.19 (I/O5), U10W24.15 (DQ6), U10W28.17 (Q5), U10W32.19 (I/O5); also elsewhere on the board
/E6: U10.16 (DQ7), U10N28.18 (Q6), U10N32.20 (I/O6), U10W24.16 (DQ7), U10W28.18 (Q6), U10W32.20 (I/O6); also elsewhere on the board
/E7: U10.17 (DQ8), U10N28.19 (Q7), U10N32.21 (I/O7), U10W24.17 (DQ8), U10W28.19 (Q7), U10W32.21 (I/O7); also elsewhere on the board
/SRAM/RAMA0: U10.3 (A5), U10N28.5 (A5), U10N32.7 (A5), U10W24.3 (A5), U10W28.5 (A5), U10W32.7 (A5); also elsewhere on the board
/SRAM/RAMA1: U10.19 (A10), U10N28.21 (A10), U10N32.23 (A10), U10W24.19 (A10), U10W28.21 (A10), U10W32.23 (A10); also elsewhere on the board
/SRAM/RAMA2: U10.4 (A4), U10N28.6 (A4), U10N32.8 (A4), U10W24.4 (A4), U10W28.6 (A4), U10W32.8 (A4); also elsewhere on the board
/SRAM/RAMA3: U10.2 (A6), U10N28.4 (A6), U10N32.6 (A6), U10W24.2 (A6), U10W28.4 (A6), U10W32.6 (A6); also elsewhere on the board
/SRAM/RAMA4: U10.23 (A8), U10N28.25 (A8), U10N32.27 (A8), U10W24.23 (A8), U10W28.25 (A8), U10W32.27 (A8); also elsewhere on the board
/SRAM/RAMA5: U10.1 (A7), U10N28.3 (A7), U10N32.5 (A7), U10W24.1 (A7), U10W28.3 (A7), U10W32.5 (A7); also elsewhere on the board
/SRAM/RAMA6: U10.6 (A2), U10N28.8 (A2), U10N32.10 (A2), U10W24.6 (A2), U10W28.8 (A2), U10W32.10 (A2); also elsewhere on the board
/SRAM/RAMA7: U10.22 (A9), U10N28.24 (A9), U10N32.26 (A9), U10W24.22 (A9), U10W28.24 (A9), U10W32.26 (A9); also elsewhere on the board
/SRAM/RAMA8: U10.7 (A1), U10N28.9 (A1), U10N32.11 (A1), U10W24.7 (A1), U10W28.9 (A1), U10W32.11 (A1); also elsewhere on the board
/SRAM/RAMA9: U10.8 (A0), U10N28.10 (A0), U10N32.12 (A0), U10W24.8 (A0), U10W28.10 (A0), U10W32.12 (A0); also elsewhere on the board
/SRAM/RAMA10: U10.5 (A3), U10N28.7 (A3), U10N32.9 (A3), U10W24.5 (A3), U10W28.7 (A3), U10W32.9 (A3); also elsewhere on the board
/SRAM/RAMA11: X21.3 (B); also elsewhere on the board
/SRAM/RAM_R/~W: U10N28.27 (~WE), U10N32.29 (~WE), U10W28.27 (~WE), U10W32.29 (~WE), X21.1 (A); also elsewhere on the board
GND: U10.12 (GND), U10.18 (~CS), U10.20 (~OE), U10N28.14 (GND), U10N28.20 (~CS), U10N28.22 (~OE), U10N32.16 (GND), U10N32.22 (~CE), U10N32.24 (~OE), U10W24.12 (GND), U10W24.18 (~CS), U10W24.20 (~OE), U10W28.14 (GND), U10W28.20 (~CS), U10W28.22 (~OE), U10W32.16 (GND), U10W32.22 (~CE), U10W32.24 (~OE); also elsewhere on the board
unnamed: U10.21 (~WE), U10N28.23 (A11), U10N32.25 (A11), U10W24.21 (~WE), U10W28.23 (A11), U10W32.25 (A11), X21.2 (C)

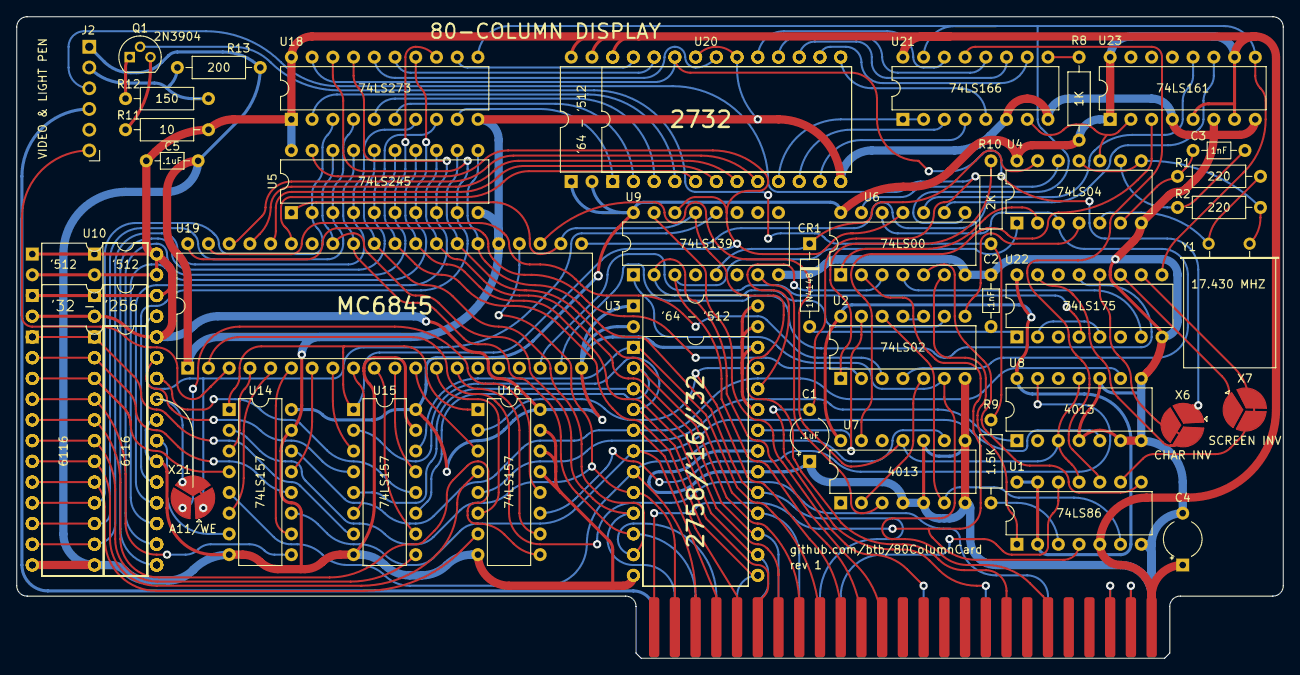
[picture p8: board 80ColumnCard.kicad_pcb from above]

Board: 2 copper layers, 155.2 x 78.6 mm, 47 parts (0 on the bottom side), 131 nets.

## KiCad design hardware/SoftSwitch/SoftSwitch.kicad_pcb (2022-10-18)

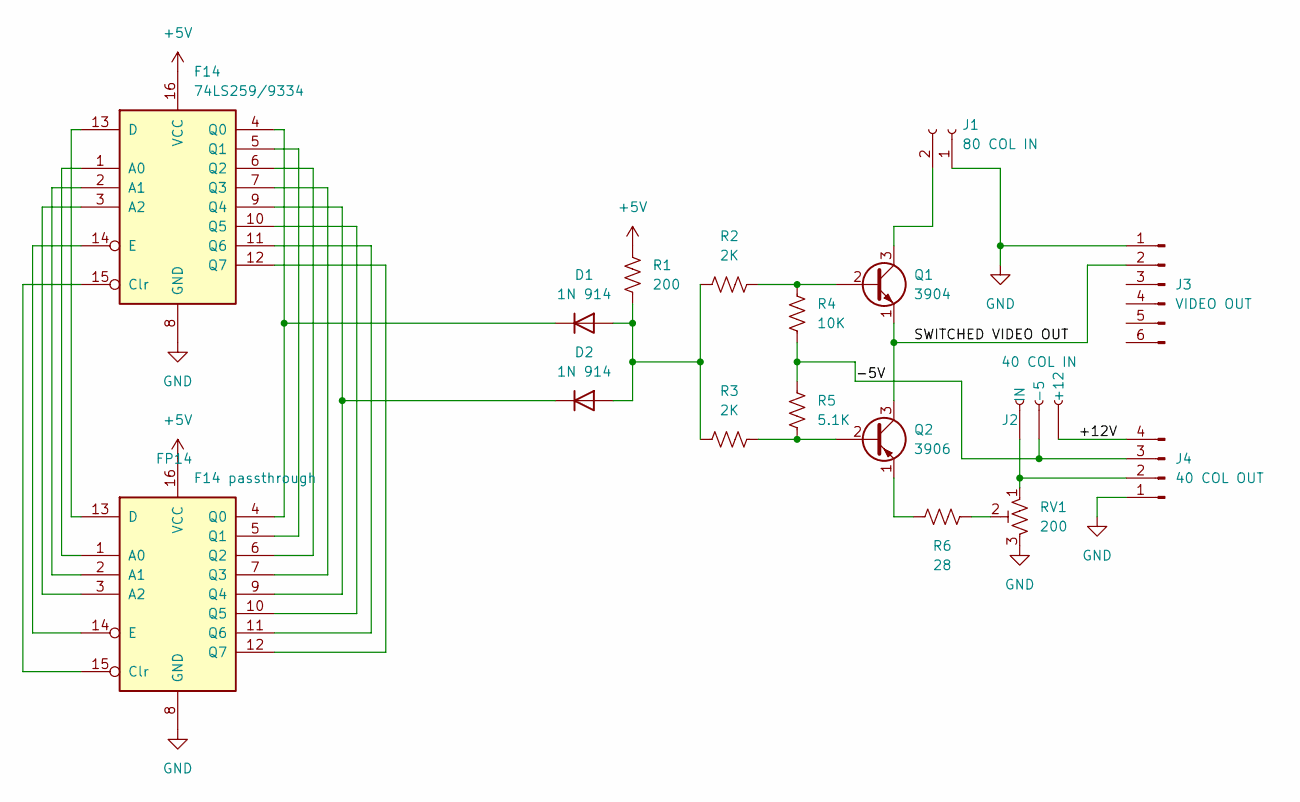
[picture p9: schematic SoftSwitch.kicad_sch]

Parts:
D1, D2: 1N 914; D_DO-35_SOD27_P10.16mm_Horizontal
F14: 74LS259/9334; DIP-16_W7.62mm_Socket
FP14: F14 passthrough; DIP-16_W7.62mm_Socket
J1: 80 COL IN; SolderWire-0.1sqmm_1x02_P3.6mm_D0.4mm_OD1mm_Relief
J2: 40 COL IN; SolderWire-0.1sqmm_1x03_P3.6mm_D0.4mm_OD1mm_Relief
J3: VIDEO OUT; PinHeader_1x06_P2.54mm_Horizontal
J4: 40 COL OUT; PinHeader_1x04_P2.54mm_Vertical
Q1: 3904; TO-92
Q2: 3906; TO-92
R1: 200; R_Axial_DIN0207_L6.3mm_D2.5mm_P10.16mm_Horizontal
R2, R3: 2K; R_Axial_DIN0207_L6.3mm_D2.5mm_P10.16mm_Horizontal
R4: 10K; R_Axial_DIN0207_L6.3mm_D2.5mm_P10.16mm_Horizontal
R5: 5.1K; R_Axial_DIN0207_L6.3mm_D2.5mm_P10.16mm_Horizontal
R6: 28; R_Axial_DIN0207_L6.3mm_D2.5mm_P10.16mm_Horizontal
RV1: 200; Multi_Potentiometer_6mm_Vertical

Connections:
+5V: F14.16 (VCC), FP14.16 (VCC), R1.2
/+12V: J2.3 (+12), J4.4
/-5V: J2.2 (-5), J4.3, R4.2, R5.1
/SWITCHED VIDEO OUT: J3.2, Q1.1 (E), Q2.3 (C)
GND: F14.8 (GND), FP14.8 (GND), J1.1, J3.1, J4.1, RV1.3
unnamed: D1.1 (K), F14.4 (Q0), FP14.4 (Q0)
unnamed: D1.2 (A), D2.2 (A), R1.1, R2.1, R3.1
unnamed: D2.1 (K), F14.9 (Q4), FP14.9 (Q4)
unnamed: F14.1 (A0), FP14.1 (A0)
unnamed: F14.2 (A1), FP14.2 (A1)
unnamed: F14.3 (A2), FP14.3 (A2)
unnamed: F14.5 (Q1), FP14.5 (Q1)
unnamed: F14.6 (Q2), FP14.6 (Q2)
unnamed: F14.7 (Q3), FP14.7 (Q3)
unnamed: F14.10 (Q5), FP14.10 (Q5)
unnamed: F14.11 (Q6), FP14.11 (Q6)
unnamed: F14.12 (Q7), FP14.12 (Q7)
unnamed: F14.13 (D), FP14.13 (D)
unnamed: F14.14 (E), FP14.14 (E)
unnamed: F14.15 (Clr), FP14.15 (Clr)
unnamed: J1.2, Q1.3 (C)
unnamed: J2.1 (IN), J4.2, RV1.1
unnamed: Q1.2 (B), R2.2, R4.1
unnamed: Q2.1 (E), R6.2
unnamed: Q2.2 (B), R3.2, R5.2
unnamed: R6.1, RV1.2

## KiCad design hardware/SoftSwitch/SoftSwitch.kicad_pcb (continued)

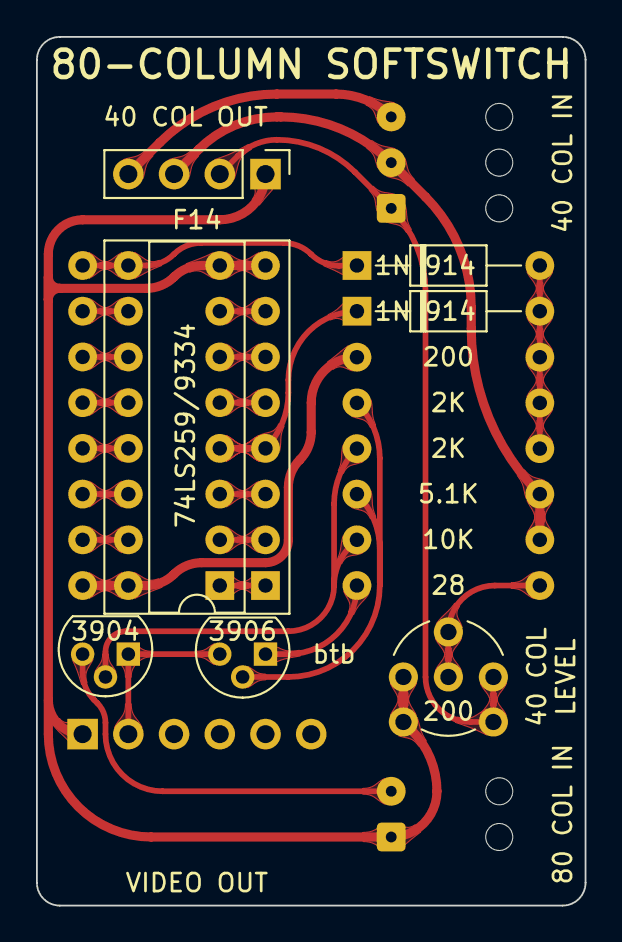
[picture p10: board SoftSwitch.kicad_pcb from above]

Board: 2 copper layers, 30.5 x 48.3 mm, 17 parts (0 on the bottom side), 26 nets.

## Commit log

2022-09-19 allow bigger RAM and ROM chips
    [80ColumnCard.kicad_pcb, 80ColumnCard.kicad_sch, char_rom.kicad_sch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]
2022-09-19 make traces for multiplexor high bit easier to cut
    [80ColumnCard.kicad_pcb]
2022-09-20 update render and BOM
2022-09-21 rename alternate char rom footprints
    [80ColumnCard.kicad_pcb, 80ColumnCard.kicad_sch, char_rom.kicad_sch]
2022-09-23 move board to "hardware" subdir
    [80ColumnCard.kicad_pcb, 80ColumnCard.kicad_sch, char_rom.kicad_sch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]
2022-09-25 connect CRTC A11 to SRAM multiplexer. add jumpers for selectable firmware
    [80ColumnCard.kicad_pcb, 80ColumnCard.kicad_sch, firmware.kicad_sch]
2022-09-26 clean up, add jumpers for fw/char selection
    [80ColumnCard.kicad_pcb, 80ColumnCard.kicad_sch, char_rom.kicad_sch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]
2022-09-27 more cleanups
    [80ColumnCard.kicad_pcb]
2022-09-27 add some annotations
    [80ColumnCard.kicad_sch]
2022-09-29 use more common component sizes
    [80ColumnCard.kicad_pcb, 80ColumnCard.kicad_sch]
2022-10-07 Add SoftSwitch
    [SoftSwitch.kicad_pcb, SoftSwitch.kicad_sch]
2022-10-08 make softswitch narrower, general improvements
    [SoftSwitch.kicad_pcb, SoftSwitch.kicad_sch]
2022-10-08 fab doc for C1,C4
    [80ColumnCard.kicad_pcb]
2022-10-08 add gerbers
    [80ColumnCard-B_Cu.gbr, 80ColumnCard-B_Mask.gbr, 80ColumnCard-B_Paste.gbr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]
2022-10-08 add revision
    [80ColumnCard-B_Cu.gbr, 80ColumnCard-B_Mask.gbr, 80ColumnCard-B_Paste.gbr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]
2022-10-09 use rev 0 image
    [80ColumnCard.kicad_pcb]
2023-05-21 add SoftSwitch gerbers
2023-05-21 add soft switch manual
2023-05-23 revert fiddling
    [80ColumnCard.kicad_pcb, 80ColumnCard.kicad_sch, char_rom.kicad_sch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]
2023-09-16 Kicad 7, miscellaneous tweaks
    [80ColumnCard.kicad_pcb, 80ColumnCard.kicad_sch, char_rom.kicad_sch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]
